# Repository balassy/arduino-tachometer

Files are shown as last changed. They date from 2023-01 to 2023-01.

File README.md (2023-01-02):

# Arduino Tachometer (RPM counter)

A rotation-per-minute counter using an Arduino (Pro Micro) board and a magnetic (Hall) sensor.

## Bill of Materials

- Arduino Pro Micro 5V (other 5V boards can work as well)
  - IMPORTANT: It must be a 5V board, because the sensor operates on this voltage level! 
- [KY-003 Hall Sensor](https://arduinomodules.info/ky-003-hall-magnetic-sensor-module/)
- Jumper wires
- M3×20 screw
- M3 nut
- 2 pieces of 8×3 magnet (8mm diameter, 3mm thick)

## How To Measure

First, create a rotating disk with magnets:

1. Print the `Tachometer Disk` model from the `3D Print` folder.

2. Insert the 2 magnets into the sockets on the disk. They should be snug fit, but you may want to cover them with tape for additional safety.

3. Insert the screw and the nut into the middle hole. It will function as a shaft.

4. Insert the shaft into the collet of the spindle you want to measure.

Second, build the measuring device:

1. Connect the Hall sensor to the Arduino:

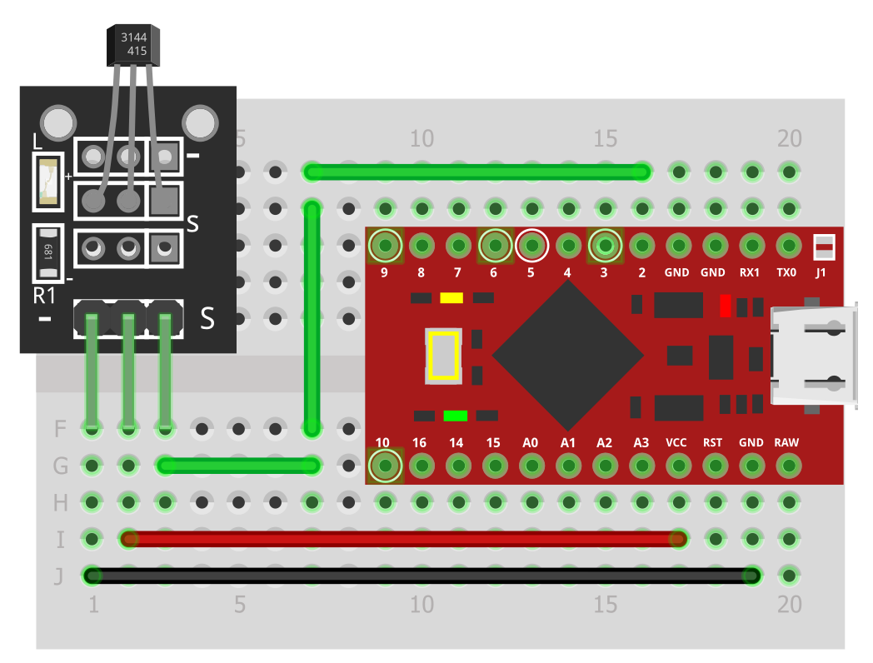
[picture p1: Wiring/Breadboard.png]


Schematic:

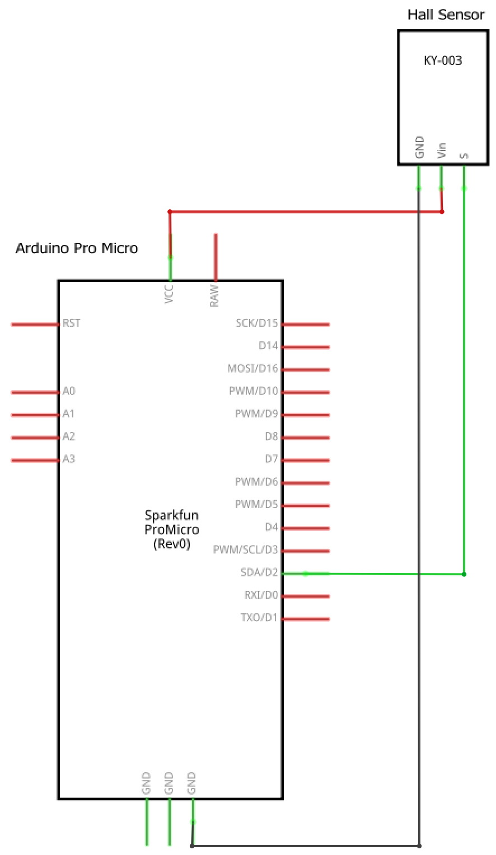
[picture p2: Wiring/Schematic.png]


2. Place the sensor close to the rotating magnets. When a magnet is close enough to the sensor the green led on the sensor board should turn on.

IMPORTANT: The sensor is directional, it can detect the magnetic field only on the side the text is written onto it!

Finally, run the code:

1. Open the code in the `Arduino` folder and upload it to the Arduino.

2. When the device boots it starts the measurement immediately and prints the results to the Serial Monitor window, so open Serial Monitor.

Enjoy :)

## Photos

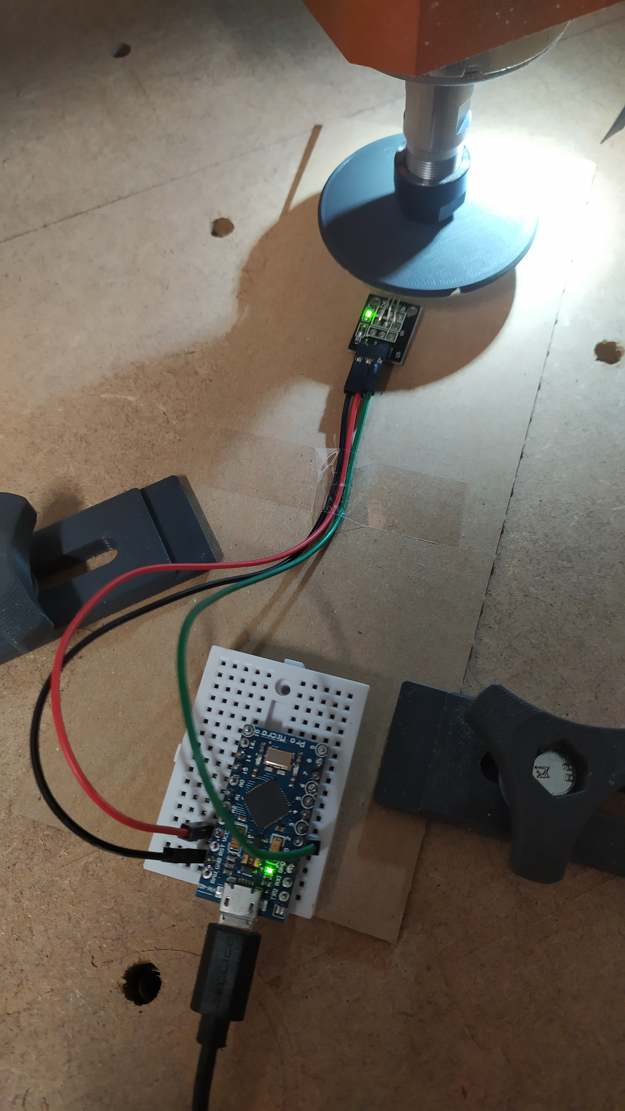
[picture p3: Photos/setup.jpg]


## For FoxAlien Users

I used this tachometer to measure the 300W spindle on my FoxAlien Masuter Pro CNC. If you have the same machine you can 3D print the `Tachometer Gauge` from the `3D Print` folder:

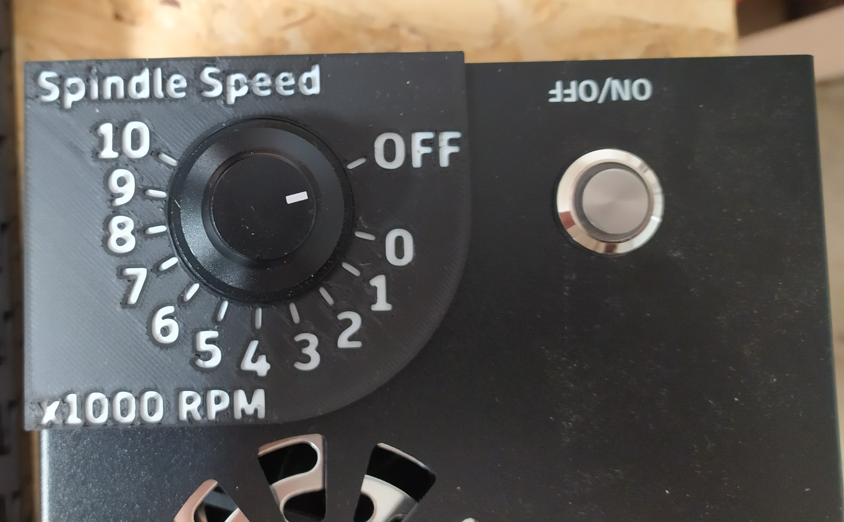
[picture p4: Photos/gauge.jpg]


Or you can use the SVG file in the `CNC` folder to cut it on your CNC:

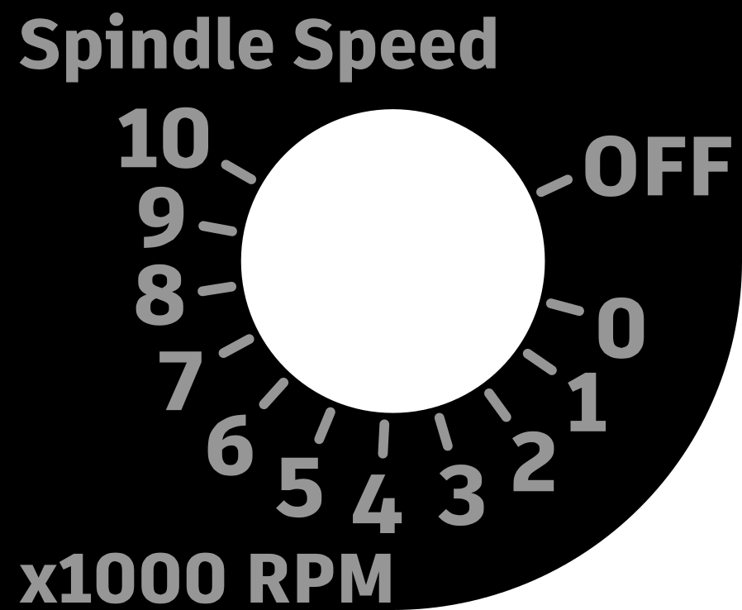
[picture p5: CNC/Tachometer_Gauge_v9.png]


## Acknowledgements

Thanks to InterlinkKnight for sharing his [Arduino Tachometer tutorial](https://www.youtube.com/watch?v=u2uJMJWsfsg).

## About the author

This project was created by [György Balássy](https://linkedin.com/in/balassy).

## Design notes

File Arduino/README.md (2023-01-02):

The code is based on InterlinkKnight's Arduino sketch:
https://www.youtube.com/watch?v=u2uJMJWsfsg

ALl thanks goes to InterlinkKnight for sharing it!

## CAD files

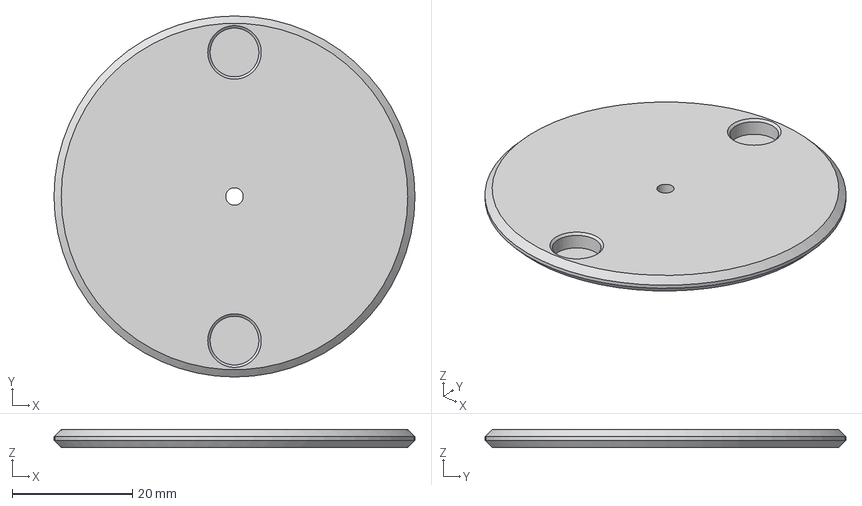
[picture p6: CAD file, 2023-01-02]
3D Print/Tachometer Disk v4.step
60.0 x 60.0 x 3.00 mm

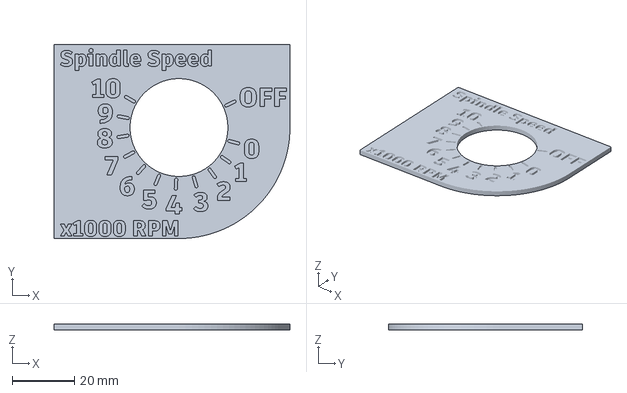
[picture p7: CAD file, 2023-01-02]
3D Print/Tachometer Gauge v9 - PrusaSlicer with color change.3mf
76.0 x 62.5 x 2.00 mm

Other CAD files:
3D Print/Tachometer Disk v4.f3d
3D Print/Tachometer Disk v4.3mf
3D Print/Tachometer Gauge v9.3mf
3D Print/Tachometer Gauge v9.f3d

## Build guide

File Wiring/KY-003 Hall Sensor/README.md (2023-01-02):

//
// ARDUINOMODULES.INFO
// KY-003 Hall Magnetic Sensor Module
//
// http://arduinomodules.info/ky-003-hall-magnetic-sensor-module/
//

File includes:
 |
 |- KY-003 Hall Magnetic Sensor Module.fzpz	//Fritzing Custom Part
 |
 |- Readme.txt					//This file 

Changelog:
  
  Oct-2020
    -Fix PCB holes.
    -Fix PCB size.
    -Fix copper layers order on PCB.

Disclaimer:

KY-003 Hall Magnetic Sensor Module Fritzing Part is created by arduinomodules.info and published under Creative Commons Attribution-ShareAlike 4.0 International license (https://creativecommons.org/licenses/by-sa/4.0/).
You can use it, share it and/or modify it for any purposes as long as you distribute it under the same license and provide appropriate credit.

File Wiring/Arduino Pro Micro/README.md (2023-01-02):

Source: https://github.com/htho/fritzing-parts/tree/master/sparkfun-promicro

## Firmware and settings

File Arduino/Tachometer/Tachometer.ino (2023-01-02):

// This sketch is using the code of InterlinkKnight from this tutorial: https://www.youtube.com/watch?v=u2uJMJWsfsg
// All credit goes to the original author for sharing his knowledge. 


// The interrupt-enabled digital pin the KY-003 Hall sensor is connected to.
// Read more about the sensor: https://arduinomodules.info/ky-003-hall-magnetic-sensor-module/
// Read more about interrupts: https://www.arduino.cc/reference/en/language/functions/external-interrupts/attachinterrupt/
int sensorPin = 2;


///////////////
// Calibration:
///////////////

const byte PulsesPerRevolution = 4;  // Set how many pulses there are on each revolution. Default: 2.


// If the period between pulses is too high, or even if the pulses stopped, then we would get stuck showing the
// last value instead of a 0. Because of this we are going to set a limit for the maximum period allowed.
// If the period is above this value, the RPM will show as 0.
// The higher the set value, the longer lag/delay will have to sense that pulses stopped, but it will allow readings
// at very low RPM.
// Setting a low value is going to allow the detection of stop situations faster, but it will prevent having low RPM readings.
// The unit is in microseconds.
const unsigned long ZeroTimeout = 100000;  // For high response time, a good value would be 100000.
                                           // For reading very low RPM, a good value would be 300000.


// Calibration for smoothing RPM:
const byte numReadings = 2;  // Number of samples for smoothing. The higher, the more smoothing, but it's going to
                             // react slower to changes. 1 = no smoothing. Default: 2.

/////////////
// Variables:
/////////////

int counter = 0;  // The number of events measured. (Useful to detect missing or duplicate events when debugging.)

volatile unsigned long LastTimeWeMeasured;  // Stores the last time we measured a pulse so we can calculate the period.
volatile unsigned long PeriodBetweenPulses = ZeroTimeout+1000;  // Stores the period between pulses in microseconds.
                       // It has a big number so it doesn't start with 0 which would be interpreted as a high frequency.
volatile unsigned long PeriodAverage = ZeroTimeout+1000;  // Stores the period between pulses in microseconds in total, if we are taking multiple pulses.
                       // It has a big number so it doesn't start with 0 which would be interpreted as a high frequency.
unsigned long FrequencyRaw;  // Calculated frequency, based on the period. This has a lot of extra decimals without the decimal point.
unsigned long FrequencyReal;  // Frequency without decimals.
unsigned long RPM;  // Raw RPM without any processing.
unsigned int PulseCounter = 1;  // Counts the amount of pulse readings we took so we can average multiple pulses before calculating the period.

unsigned long PeriodSum; // Stores the summation of all the periods to do the average.

unsigned long LastTimeCycleMeasure = LastTimeWeMeasured;  // Stores the last time we measure a pulse in that cycle.
                                    // We need a variable with a value that is not going to be affected by the interrupt
                                    // because we are going to do math and functions that are going to mess up if the values
                                    // changes in the middle of the cycle.
unsigned long CurrentMicros = micros();  // Stores the micros in that cycle.
                                         // We need a variable with a value that is not going to be affected by the interrupt
                                         // because we are going to do math and functions that are going to mess up if the values
                                         // changes in the middle of the cycle.

// We get the RPM by measuring the time between 2 or more pulses so the following will set how many pulses to
// take before calculating the RPM. 1 would be the minimum giving a result every pulse, which would feel very responsive
// even at very low speeds but also is going to be less accurate at higher speeds.
// With a value around 10 you will get a very accurate result at high speeds, but readings at lower speeds are going to be
// farther from eachother making it less "real time" at those speeds.
// There's a function that will set the value depending on the speed so this is done automatically.
unsigned int AmountOfReadings = 1;

unsigned int ZeroDebouncingExtra;  // Stores the extra value added to the ZeroTimeout to debounce it.
                                   // The ZeroTimeout needs debouncing so when the value is close to the threshold it
                                   // doesn't jump from 0 to the value. This extra value changes the threshold a little
                                   // when we show a 0.

// Variables for smoothing tachometer:
unsigned long readings[numReadings];  // The input.
unsigned long readIndex;  // The index of the current reading.
unsigned long total;  // The running total.
unsigned long average;  // The RPM value after applying the smoothing.




void setup()
{
  Serial.begin(9600);

  attachInterrupt(digitalPinToInterrupt(sensorPin), Pulse_Event, CHANGE);

  delay(1000);  // We sometimes take several readings of the period to average. Since we don't have any readings
                // stored we need a high enough value in micros() so if divided is not going to give negative values.
                // The delay allows the micros() to be high enough for the first few cycles.

  Serial.println("Setup DONE.");
}


void loop()
{
	// The following is going to store the two values that might change in the middle of the cycle.
  // We are going to do math and functions with those values and they can create glitches if they change in the
  // middle of the cycle.
  LastTimeCycleMeasure = LastTimeWeMeasured;  // Store the LastTimeWeMeasured in a variable.
  CurrentMicros = micros();  // Store the micros() in a variable.

  // CurrentMicros should always be higher than LastTimeWeMeasured, but in rare occasions that's not true.
  // I'm not sure why this happens, but my solution is to compare both and if CurrentMicros is lower than
  // LastTimeCycleMeasure I set it as the CurrentMicros.
  // The need of fixing this is that we later use this information to see if pulses stopped.
  if(CurrentMicros < LastTimeCycleMeasure)
  {
    LastTimeCycleMeasure = CurrentMicros;
  }

  // Calculate the frequency:
  FrequencyRaw = 10000000000 / PeriodAverage;  // Calculate the frequency using the period between pulses.

  // Detect if pulses stopped or frequency is too low, so we can show 0 Frequency:
  if(PeriodBetweenPulses > ZeroTimeout - ZeroDebouncingExtra || CurrentMicros - LastTimeCycleMeasure > ZeroTimeout - ZeroDebouncingExtra)
  {  // If the pulses are too far apart that we reached the timeout for zero:
    FrequencyRaw = 0;  // Set frequency as 0.
    ZeroDebouncingExtra = 2000;  // Change the threshold a little so it doesn't bounce.
  }
  else
  {
    ZeroDebouncingExtra = 0;  // Reset the threshold to the normal value so it doesn't bounce.
  }

  FrequencyReal = FrequencyRaw / 10000;  // Get frequency without decimals.
                                          // This is not used to calculate RPM but we remove the decimals just in case
                                          // you want to print it.

  // Calculate the RPM:
  RPM = FrequencyRaw / PulsesPerRevolution * 60;  // Frequency divided by amount of pulses per revolution multiply by
                                                  // 60 seconds to get minutes.
  RPM = RPM / 10000;  // Remove the decimals.

  // Smoothing RPM:
  total = total - readings[readIndex];  // Advance to the next position in the array.
  readings[readIndex] = RPM;  // Takes the value that we are going to smooth.
  total = total + readings[readIndex];  // Add the reading to the total.
  readIndex = readIndex + 1;  // Advance to the next position in the array.

  if (readIndex >= numReadings)  // If we're at the end of the array:
  {
    readIndex = 0;  // Reset array index.
  }
  
  // Calculate the average:
  average = total / numReadings;  // The average value it's the smoothed result.

  // Print information on the serial monitor:
  // Comment this section if you have a display and you don't need to monitor the values on the serial monitor.
  // This is because disabling this section would make the loop run faster.
  Serial.print("Period: ");
  Serial.print(PeriodBetweenPulses);
  Serial.print("\tReadings: ");
  Serial.print(AmountOfReadings);
  Serial.print("\tFrequency: ");
  Serial.print(FrequencyReal);
  Serial.print("\tRPM: ");
  Serial.print(RPM);
  Serial.print("\tTachometer: ");
  Serial.print(average);
  Serial.print("\tCount: ");
  Serial.println(counter);
}



void Pulse_Event()  // The interrupt runs this to calculate the period between pulses:
{
  counter++;

  PeriodBetweenPulses = micros() - LastTimeWeMeasured;  // Current "micros" minus the old "micros" when the last pulse happens.
                                                        // This will result with the period (microseconds) between both pulses.
                                                        // The way is made, the overflow of the "micros" is not going to cause any issue.

  LastTimeWeMeasured = micros();  // Stores the current micros so the next time we have a pulse we would have something to compare with.

  if(PulseCounter >= AmountOfReadings)  // If counter for amount of readings reach the set limit:
  {
    PeriodAverage = PeriodSum / AmountOfReadings;  // Calculate the final period dividing the sum of all readings by the
                                                   // amount of readings to get the average.
    PulseCounter = 1;  // Reset the counter to start over. The reset value is 1 because its the minimum setting allowed (1 reading).
    PeriodSum = PeriodBetweenPulses;  // Reset PeriodSum to start a new averaging operation.

    // Change the amount of readings depending on the period between pulses.
    // To be very responsive, ideally we should read every pulse. The problem is that at higher speeds the period gets
    // too low decreasing the accuracy. To get more accurate readings at higher speeds we should get multiple pulses and
    // average the period, but if we do that at lower speeds then we would have readings too far apart (laggy or sluggish).
    // To have both advantages at different speeds, we will change the amount of readings depending on the period between pulses.
    // Remap period to the amount of readings:
    int RemapedAmountOfReadings = map(PeriodBetweenPulses, 40000, 5000, 1, 10);  // Remap the period range to the reading range.
    // 1st value is what are we going to remap. In this case is the PeriodBetweenPulses.
    // 2nd value is the period value when we are going to have only 1 reading. The higher it is, the lower RPM has to be to reach 1 reading.
    // 3rd value is the period value when we are going to have 10 readings. The higher it is, the lower RPM has to be to reach 10 readings.
    // 4th and 5th values are the amount of readings range.
    RemapedAmountOfReadings = constrain(RemapedAmountOfReadings, 1, 10);  // Constrain the value so it doesn't go below or above the limits.
    AmountOfReadings = RemapedAmountOfReadings;  // Set amount of readings as the remaped value.
  }
  else
  {
    PulseCounter++;  // Increase the counter for amount of readings by 1.
    PeriodSum = PeriodSum + PeriodBetweenPulses;  // Add the periods so later we can average.
  }
}  // End of Pulse_Event.
